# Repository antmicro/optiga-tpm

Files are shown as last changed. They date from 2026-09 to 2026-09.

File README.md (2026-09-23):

# Optiga TPM Module

Copyright (c) 2026 [Antmicro](https://www.antmicro.com)

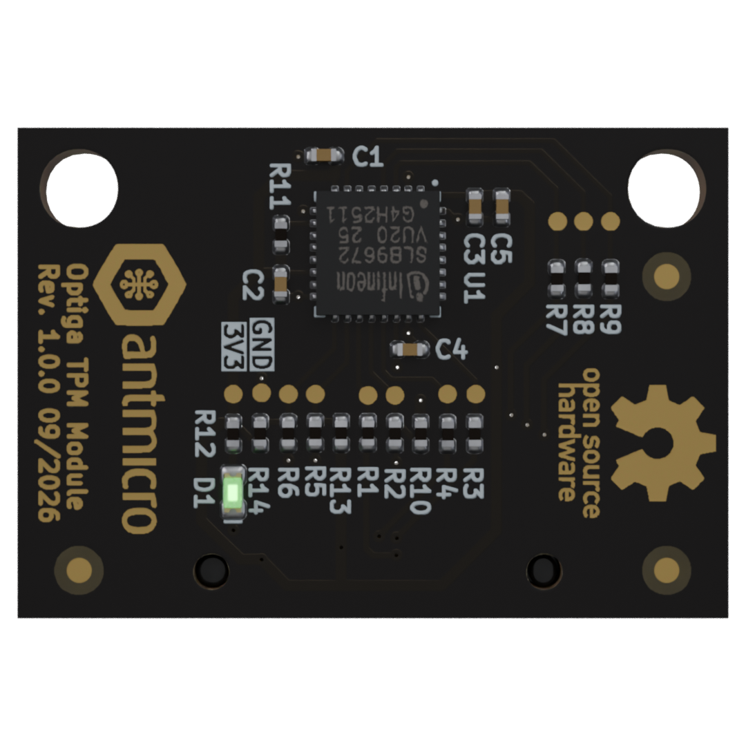
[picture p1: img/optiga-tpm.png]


## Overview

This project contains open hardware design files for a TPM 2.0 module based on the Infineon OPTIGA TPM SLB 9672. TPM module provides an SPI-connected TPM 2.0 IC for embedded systems, IoT, networking equipment, telecommunications infrastructure and consumer electronics.
It provides a foundation for securely establihing the identity and software status of connected devices.

The board connects to a host via SPI protocol and 3 GPIO pins. 
The Optiga TPM Module can be connected to various platforms with ERF5 40-pin board to board connector. All signals are exposed on testpads. 

The PCB design files were prepared in KiCad 10.x.

## Key features

* Trusted Platform Module (TPM) 2.0 compliant
* PQC-protected firmware update mechanism
* 40-pin ERF5 connector (compatible with Antmicro CM4 Baseboard)
* All signals exposed on testpads 
* 20 x 29 mm (0.78 x 1.14 inch) PCB outline

## Project structure

The main directory contains KiCad PCB project files, the LICENSE, and this README, and the img directory contains graphics for this README.

## License

This project is licensed under the [Apache-2.0](LICENSE) license.

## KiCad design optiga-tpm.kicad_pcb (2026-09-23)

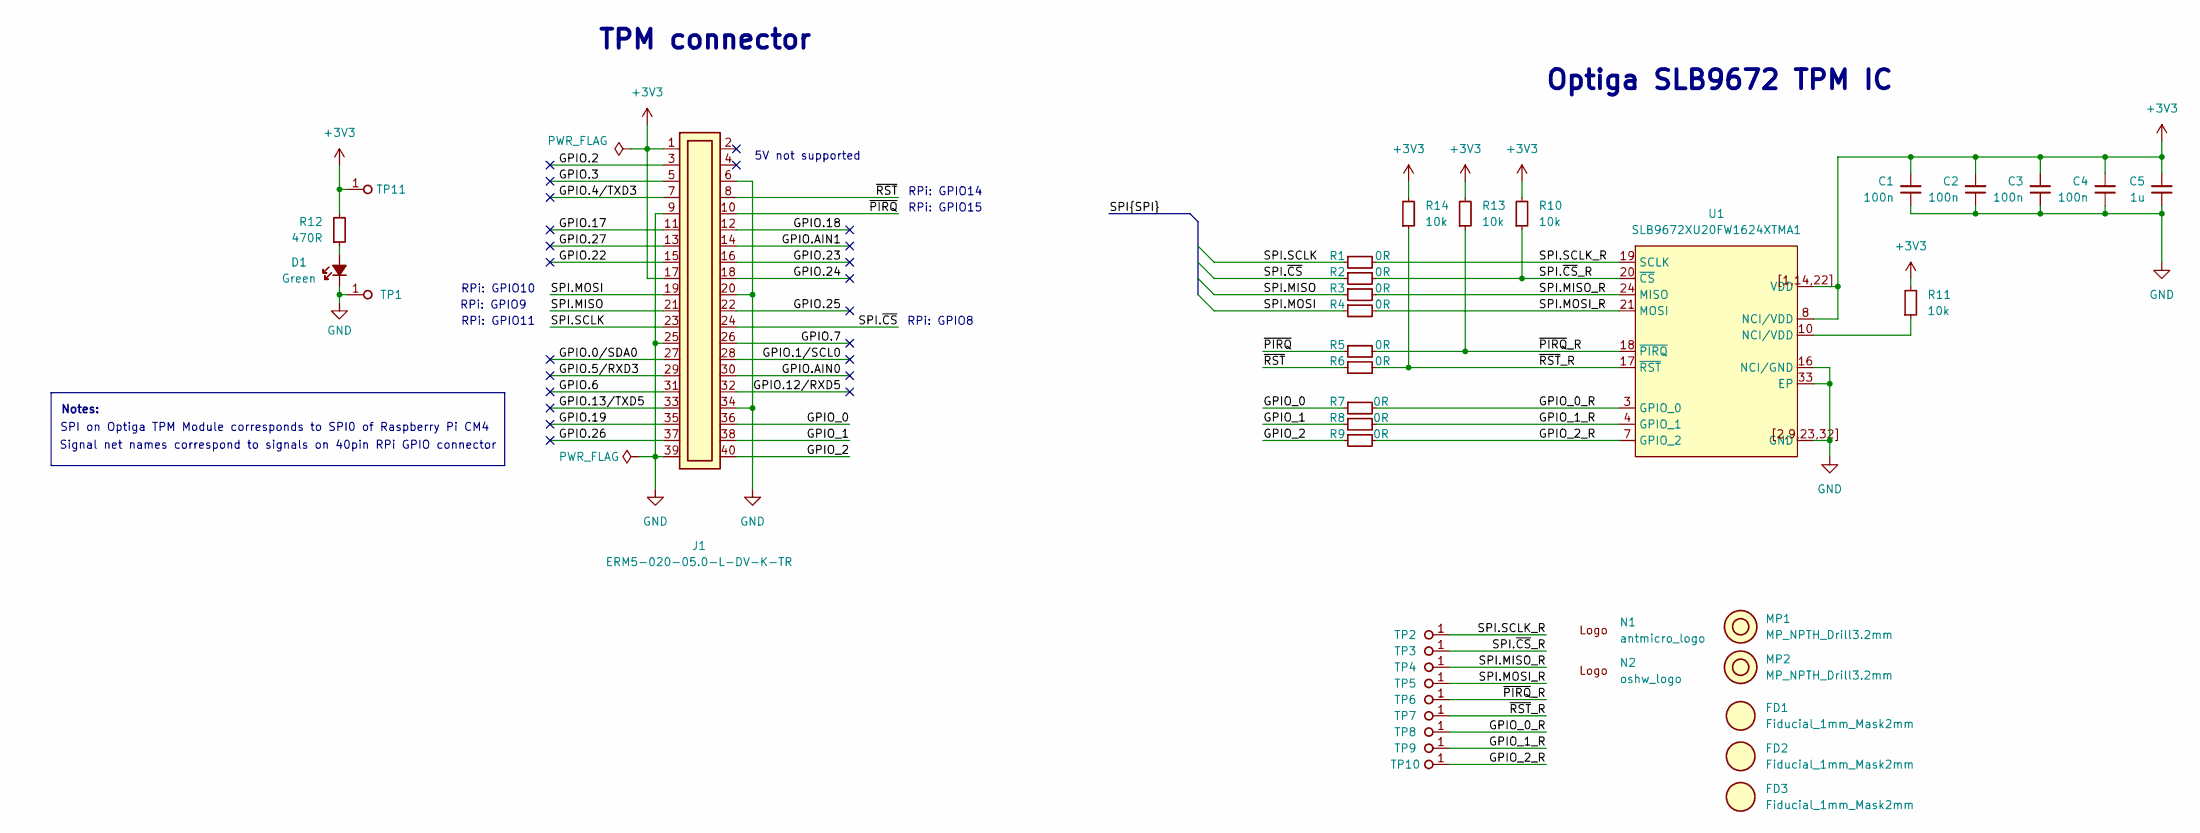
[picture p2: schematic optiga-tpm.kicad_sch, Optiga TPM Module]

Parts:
C1, C2, C3, C4: C_100n_25V_0402; C_0402_1005Metric; Voltage 25V; MPN CL05A104KA5NNNC
C5: C_1u_10V_X7R_0402; C_0402_1005Metric; Voltage 10V; MPN GRM155Z71A105KE01D
D1: LED_G_0603_KP-1608CGCK; LED_0603_1608Metric_G; MPN KP-1608CGCK
FD1, FD2, FD3: Fiducial_1mm_Mask2mm
J1: Plug_Samtec_ERM5_2x20_ERM5-020-05.0-L-DV-K-TR; Conn_Plug_Samtec_ERM5_2x20_ERM5-020-05.0-L-DV-K-TR; MPN ERM5-020-05.0-L-DV-K-TR
MP1, MP2: MP_NPTH_Drill3.2mm
N1: antmicro_logo; antmicro-logo_scaled_12mm
N2: oshw_logo; oshw-logo
R1, R2, R3, R4, R5, R6, R7, R8, R9: R_0R_0402; R_0402_1005Metric; MPN ERJ2GE0R00X
R10, R11, R13, R14: R_10k_0402; R_0402_1005Metric; Tolerance 1%; MPN CR0402-FX-1002GLF
R12: R_470R_0402; R_0402_1005Metric; Tolerance 1%; MPN CR0402-FX-4700GLF
TP1, TP2, TP3, TP4, TP5, TP6, TP7, TP8, TP9, TP10, TP11: TP_0.75mm_SMD; TP_SMD_0.75mm
U1: SLB9672XU20FW1624XTMA1; UQFN-32-1EP_5x5mm_P0.5mm_EP3.6x3.6mm; MPN SLB9672XU20FW1624XTMA1

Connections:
+3V3: C1.2, C2.2, C3.2, C4.2, C5.2, J1.1, J1.17, R10.2, R11.2, R12.2, R13.2, R14.2, TP11.1 (1_1), U1.1 (VDD), U1.8 (NCI/VDD), U1.14 (VDD), U1.22 (VDD), U1.[1,14,22] (VDD)
/GPIO.0/SDA0: J1.27
/GPIO.1/SCL0: J1.28
/GPIO.2: J1.3
/GPIO.3: J1.5
/GPIO.4/TXD3: J1.7
/GPIO.5/RXD3: J1.29
/GPIO.6: J1.31
/GPIO.7: J1.26
/GPIO.12/RXD5: J1.32
/GPIO.13/TXD5: J1.33
/GPIO.17: J1.11
/GPIO.18: J1.12
/GPIO.19: J1.35
/GPIO.22: J1.15
/GPIO.23: J1.16
/GPIO.24: J1.18
/GPIO.25: J1.22
/GPIO.26: J1.37
/GPIO.27: J1.13
/GPIO.AIN0: J1.30
/GPIO.AIN1: J1.14
/GPIO_0: J1.36, R7.1
/GPIO_0_R: R7.2, TP8.1 (1_1), U1.3 (GPIO_0)
/GPIO_1: J1.38, R8.1
/GPIO_1_R: R8.2, TP9.1 (1_1), U1.4 (GPIO_1)
/GPIO_2: J1.40, R9.1
/GPIO_2_R: R9.2, TP10.1 (1_1), U1.7 (GPIO_2)
/SPI.MISO: J1.21, R3.1
/SPI.MISO_R: R3.2, TP4.1 (1_1), U1.24 (MISO)
/SPI.MOSI: J1.19, R4.1
/SPI.MOSI_R: R4.2, TP5.1 (1_1), U1.21 (MOSI)
/SPI.SCLK: J1.23, R1.1
/SPI.SCLK_R: R1.2, TP2.1 (1_1), U1.19 (SCLK)
/SPI.~CS: J1.24, R2.1
/SPI.~CS_R: R2.2, R10.1, TP3.1 (1_1), U1.20 (~CS)
/~PIRQ: J1.10, R5.1
/~PIRQ_R: R5.2, R13.1, TP6.1 (1_1), U1.18 (~PIRQ)
/~RST: J1.8, R6.1
/~RST_R: R6.2, R14.1, TP7.1 (1_1), U1.17 (~RST)
GND: C1.1, C2.1, C3.1, C4.1, C5.1, D1.1 (C), J1.6, J1.9, J1.20, J1.25, J1.34, J1.39, TP1.1 (1_1), U1.2 (GND), U1.9 (GND), U1.16 (NCI/GND), U1.23 (GND), U1.32 (GND), U1.33 (EP), U1.[2,9,23,32] (GND)
unnamed: D1.2 (A), R12.1
unnamed: R11.1, U1.10 (NCI/VDD)

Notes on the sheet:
RPi: GPIO8
RPi: GPIO15
Optiga SLB9672 TPM IC
RPi: GPIO9
Signal net names correspond to signals on 40pin RPi GPIO connector
TPM connector
5V not supported
RPi: GPIO10
RPi: GPIO11
SPI on Optiga TPM Module corresponds to SPI0 of Raspberry Pi CM4
RPi: GPIO14
Notes:

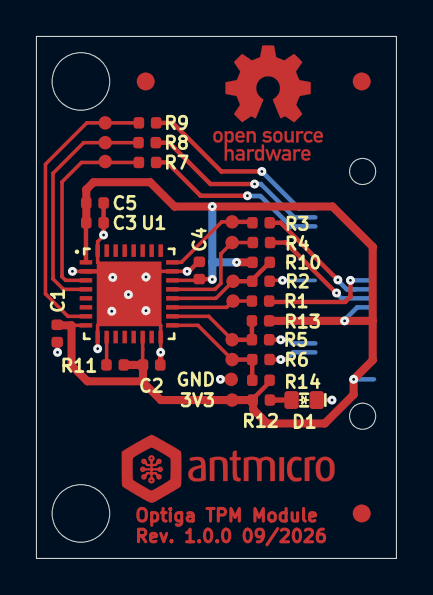
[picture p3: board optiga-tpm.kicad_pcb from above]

Board: 2 copper layers, 20.0 x 29.0 mm, 40 parts (1 on the bottom side), 22 nets.

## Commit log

2026-09-09 [#104798] Init project
    [cm4-baseboard-tpm-module.kicad_pcb, cm4-baseboard-tpm-module.kicad_sch]
2026-09-09 [#104798] Add SLB9672 and gpio connector to schematic
    [cm4-baseboard-tpm-module.kicad_pcb, cm4-baseboard-tpm-module.kicad_sch]
2026-09-10 [#104798] Update SLB9672 symbol, finish schematic
    [cm4-baseboard-tpm-module.kicad_sch]
2026-09-10 [#104798] Make full placement and layout, clear DRC
    [cm4-baseboard-tpm-module.kicad_pcb, cm4-baseboard-tpm-module.kicad_sch]
2026-09-10 [#104798] Add measurements, bump date
    [cm4-baseboard-tpm-module.kicad_pcb, cm4-baseboard-tpm-module.kicad_sch]
2026-09-10 [#104798] Change board dimensions, add VCC LED, OSHW logo, ficudials and testpoints
    [cm4-baseboard-tpm-module.kicad_sch]
2026-09-10 [#104798] Clear DRC
    [cm4-baseboard-tpm-module.kicad_pcb, cm4-baseboard-tpm-module.kicad_sch]
2026-09-10 [#104798] Add testpoints and reroute the PCB
    [cm4-baseboard-tpm-module.kicad_pcb, cm4-baseboard-tpm-module.kicad_sch]
2026-09-11 [#104798] Change SLB9672 3D model
    [cm4-baseboard-tpm-module.kicad_pcb]
2026-09-11 [#104798] Create 2-layer board version
    [cm4-baseboard-tpm-module.kicad_pcb, cm4-baseboard-tpm-module.kicad_sch]
2026-09-14 [#104798] Rename project, add pullups on PIRQ and RST, add notes, bump date
    [optiga-tpm-module.kicad_pcb, optiga-tpm-module.kicad_sch]
2026-09-14 [#104798] Delete old files, add .history to .gitignore, modify README
    [cm4-baseboard-tpm-module.kicad_pcb, cm4-baseboard-tpm-module.kicad_sch]
2026-09-14 [#104798] Change PCB stackup, clean up vias and traces according to review
    [optiga-tpm-module.kicad_pcb, optiga-tpm-module.kicad_sch]
2026-09-14 [#104798] Change via drill size from 0.1to 0.15mm
    [optiga-tpm-module.kicad_pcb]
2026-09-14 [#104798] Change via size from 0.45 to 0.5mm
    [optiga-tpm-module.kicad_pcb]
2026-09-14 [#104798] Clean up the schematic, add termal vias to IC
    [optiga-tpm-module.kicad_pcb, optiga-tpm-module.kicad_sch]
2026-09-14 [#104798] pcb: import TP1 from schematic, remove duplicate
    [optiga-tpm-module.kicad_pcb]
2026-09-23 Rename project
    [optiga-tpm.kicad_pcb, optiga-tpm.kicad_sch]
2026-09-23 Adjust dimensions position
    [optiga-tpm.kicad_pcb]

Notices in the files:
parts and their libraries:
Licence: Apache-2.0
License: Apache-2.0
